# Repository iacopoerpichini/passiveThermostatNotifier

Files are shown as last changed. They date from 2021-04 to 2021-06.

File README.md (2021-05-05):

# passiveThermostatNotifier



### About

This project provides a new interface for notifications using the idea of Ubiquitous Computing in smart home system.
It is realized with a Micro Controller with a Wi-fi module onboard, it is designed for all type of sensor and show the notification in passive way with a RGB Wi-Fi bulb.
In this case the bulb is related to a temperature sensor and the notification are about how much cold or hotter the house is.
The thermostat system it is built using low-cost components and Open Source platformsto make it reproduced by everyone.

In this project are developed a physical device and an interface via a Telegram bot.

The [documentation.pdf](https://github.com/iacopoerpichini/passiveThermostatNotifier/blob/master/documentation.pdf) provided can be used like a manual to build the whole system.

### Directories Layout

```bash
├── 3DModel                             # contains two file tipe of box model
│   ├── stl
│   ├── ctb
├── Sensor Library and Examples         # a series of sensors library to remake this project
│   ├── DHT                             # sensor used in thermostat device          
│   ├── ...
├── UniversalTelegramBot-1.3.0 Library  # used to make the Telegram bot
├── img                                 # image used in readme/paper
│   ├── ...
├── documentation.pdf                   # guide to reproduce all the work
├── firmaware.ino                       # node mcu v1.0 firmware made with arduino ide
```

#### Device
The device can be installed in an environment connected to a smart bulb that changes color and light intensity in relation to the temperature measured by a sensor.
The light bulb color changes slowly.
The device has a temperature sensor, a WiFi connection, a buzzer to receive active notification via interaction with an interface and a button to stop the change of color bulb.
There is also a build-in led that displays in real time the state of the temperature sensor.
#### Render of 3D model
In this repo are provided all the 3D file used to print the cover of the device.

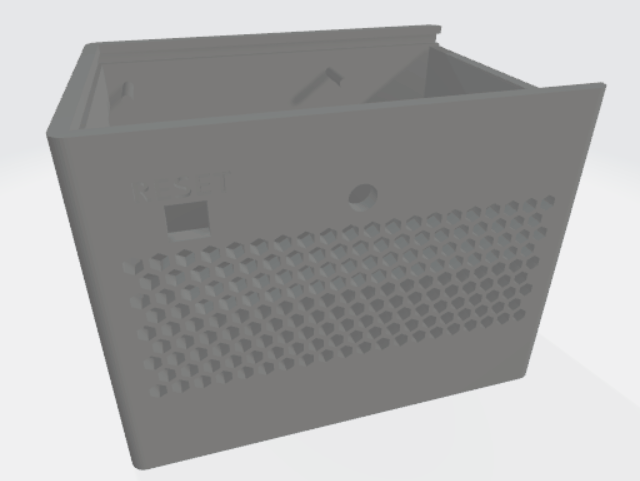
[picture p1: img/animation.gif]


#### Telegram bot
The bot allows users to get real-time information about temperature and humidity.
Furthermore, it is also possible to select the desired temperature bound to change the bulb color.
By default, temperature bounds are set on [16,24] Celsius degree.
The bulb turns to red slowly if the temperature is higher than 24 degree and turns blue if is lower than 16 degree.
It is also possible to notify people near the sensor with a buzzer.

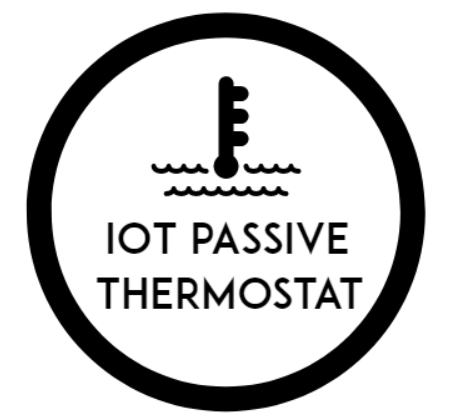
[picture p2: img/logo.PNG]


To create a Telegram bot:
  1. Open BotFather available at this [link](https://t.me/botfather)
  2. Click the start button and type `/newbot`.
    - Then follow the instructions to create your bot. Give it a name and username.
  3. If your bot is successfully created, you’ll receive a message with a link to access the bot and the bot token.

Anyone that knows your bot username can interact with it. 

To make sure that the bot ignore messages that are not from any authorized users, you can get your Telegram User ID.
Then, when your telegram bot receives a message, the ESP can check whether the sender ID corresponds to your User ID and handle the message or ignore it.
Open [IDBot](t.me/myidbot) and type `/getid` and use it in the firmware.

#### ThingSpeak

The device also use a ThingSpeak channel available [here](https://thingspeak.com/channels/1367465) to display all the data collected.

To make a Channel follow the[ThingSpeak Official Documentation](https://www.mathworks.com/help/thingspeak/collect-data-in-a-new-channel.html).

### Requirements
| Software | Version |
| ---|---|
| **Arduino IDE** | tested on v1.8.3 | 
| **ESP8266** | tested on v2.5.2 | 
| **ArduinoJson** | tested on v6.17.3 | 
| **Universal Telegram Bot Library** | tested on v1.3.0 | 

To install ESP8266 Add-on in Arduino IDE:
  1. Go to File > Preferences
  2. Enter `http://arduino.esp8266.com/stable/package_esp8266com_index.json` into the “Additional Boards Manager URLs” field. Then, click the “OK” button.
  3. Open the Boards Manager. Go to Tools > Board > Boards Manager
  4. Search and install ESP8266 by ESP8266 Community library
  5. Use Generic ESP8266 Board in Tools
  
Also install the ArduinoJson and Universal Telegram Bot Librarys.

  1. Go to Skech > Include Library > Manage Libraries.
  2. Search library.
  3. Check the version and install the library.

### Usage
The first part of the Sketch is a highly commented setup code
There are some global variables that need to be changed.
These parameters are the Network SSID and password, the IP address of light bulb, the Telegram credential mentioned before and an extra public API token to make an integration with ThingSpeak, which is an optional tool.

After you have flash the code on the device and built the circuit, start chatting with the bot.

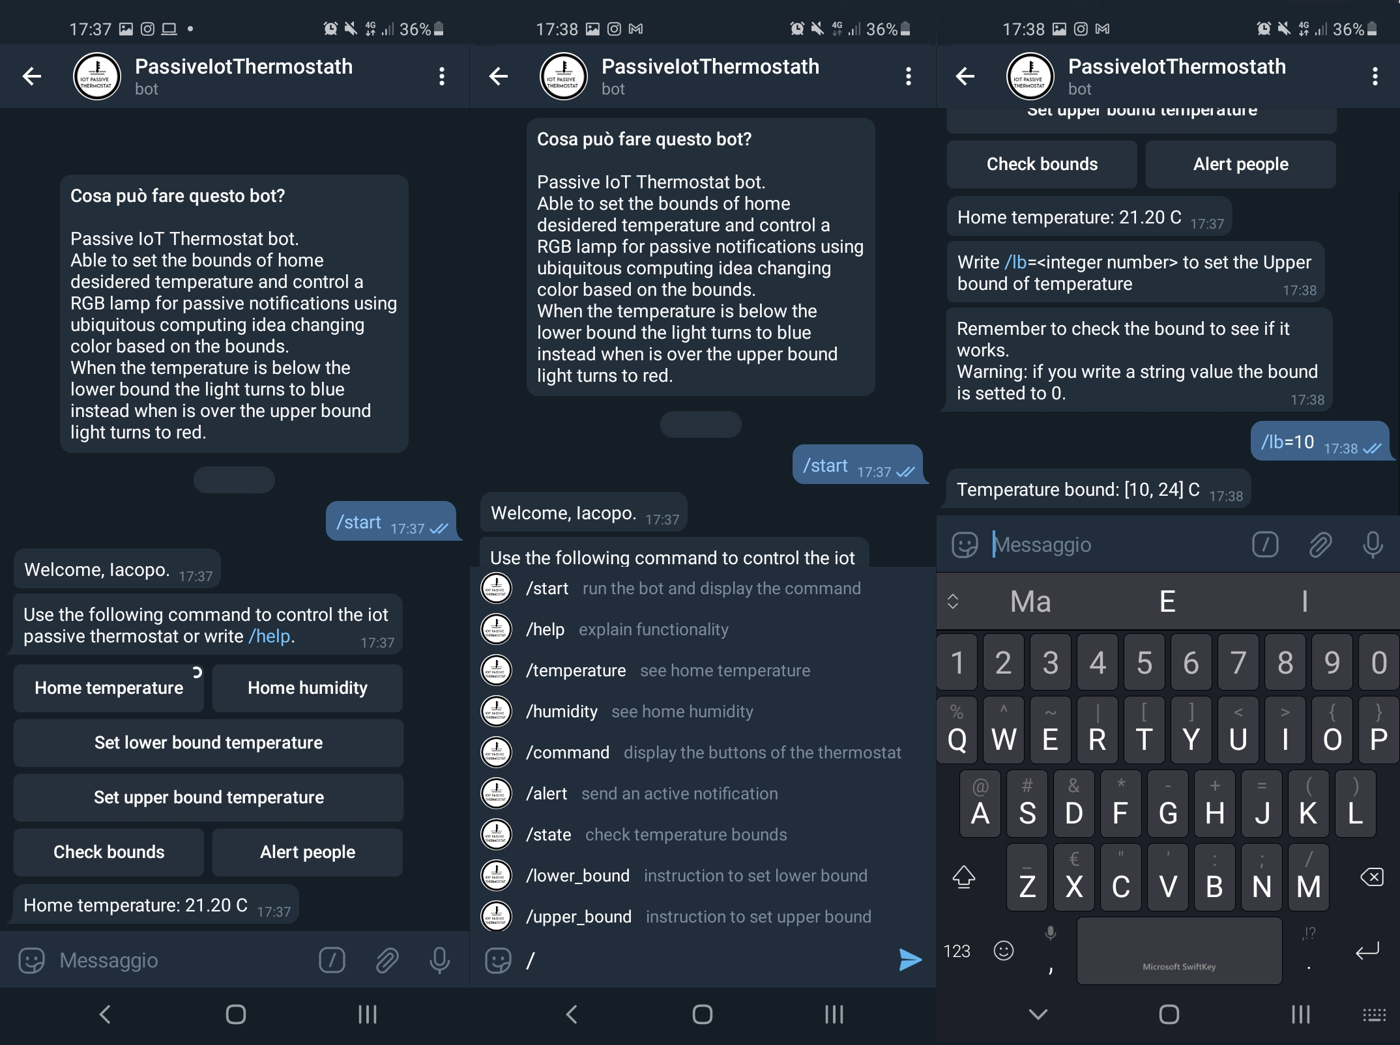
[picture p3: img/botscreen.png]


### The Telegram Keyboard
Most of the commands in the telegram Keyboard are displayed.

| Command | Description |
| ---|---|
| **/start** | run the bot and display the command| 
| **/help** | explain functionality | 
| **/temperature** | see home temperature | 
| **/humidity** | see home humidity | 
| **/command** | display the button of thermostat | 
| **/alert** | send an active notification | 
| **/state** | check temperature bound | 
| **/lower_bound** | instruction to set lower bound |  
| **/upper_bound** | instruction to set upper bound | 
| **/lb=\<Integer\>** | real method to set lower bound | 
| **/ub=\<Integer\>** | real method to set upper bound | 

#### Thanks
I want to thank my childhood friend Andrea for giving me the opportunity to 3D print the model.

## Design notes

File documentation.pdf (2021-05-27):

# IoT Thermostat with Passive Notification System

Iacopo Erpichini
Universita degli Studi di Firenze ` Computer Engineering
iacopo.erpichini@stud.unifi.it

Abstract—This paper provides a new interface for notifications using the idea of Ubiquitous computing in a smart home system. It is realized with a Micro Controller with a Wi-fi module on board, it is designed for all types of sensors and shows the notification passively with an RGB Wi-Fi bulb. In this case, the bulb is connected to a temperature sensor and the notification are about the measured temperature by the sensor. Substantially how much cold or hot the house is. The thermostat system is built using low-cost components and Open Source platforms to make it reproducible by everyone.
In this project have been developed a physical device and an interface via a Telegram bot.
Index Terms—IoT, NodeMcu ESP-12, Arduino, Ubiquitous computing, domotic system, Telegram
I. INTRODUCTION

The Internet of Things is creating much buzz while it goes about transforming our lives. IoT is everywhere, even though we do not always see it or know that a device is part of the IoT. Furthermore, the Internet of Things is turning physical object into a complete ecosystem of information, shared between devices that are wearable, portable, and even implantable, turning our lives rich of technology and data.
Nowadays, the smartest IoT home automation devices allow users to control them via an app or even via voice commands. The purpose of this paper is to build a IoT system for passive notification using the idea of Ubiquitous computing [1] (or ”ubicomp”) that is a concept in software engineering and computer science where computing is made to appear anytime and everywhere.
In this case the system wants to control a simple IoT device that is an RGB bulb with Wi-Fi module build in to make passive notification using the property of the bulb of changing color and brightness in a certain range of time.
The core of the system is a chip named Node Mcu v1.0 ESP-12 presents in Figure [1].
The system is designed to be built using low-cost components and Open Source platforms in such a way as to be simply reproduced by a user with few computer skills.
The micro controller can be programmed via Arduino IDE [2], the code is written in C++ with an addition of special methods, functions and libraries, to integrate every sensor of the project. The ’sketch’ (the name given to Arduino code files) created, it is processed and compiled to machine language and flashed on board via the IDE.

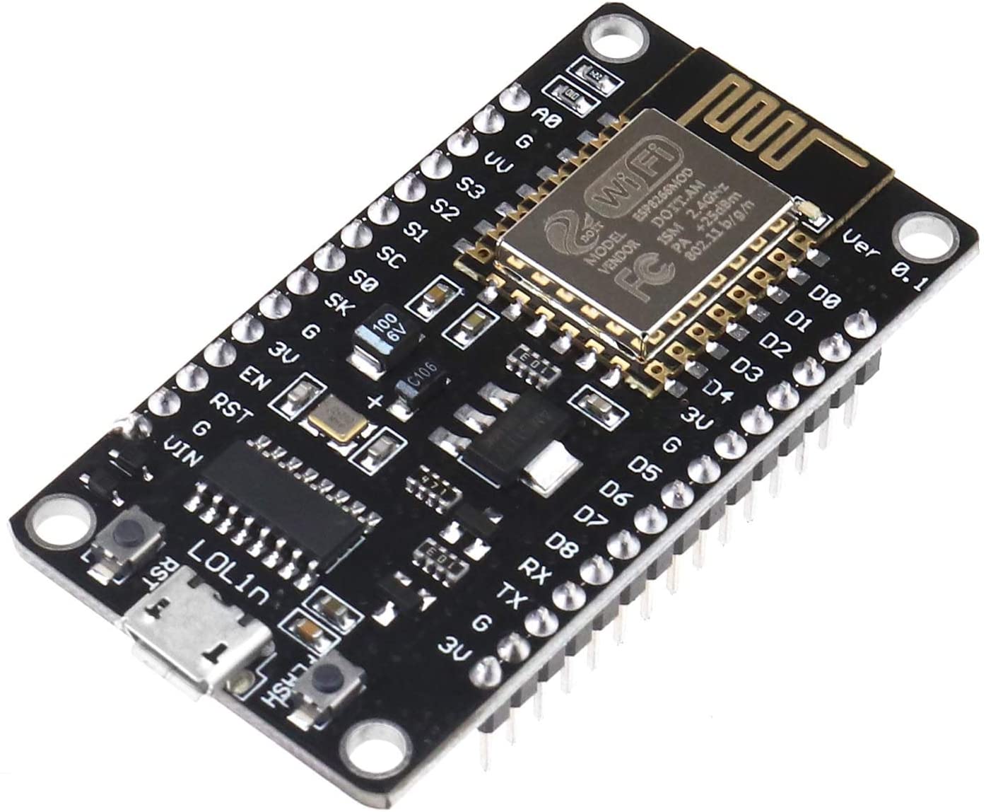
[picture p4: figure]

Fig. 1. Node Mcu V1.0 ESP-12 with ESP 8266 Wi-Fi chip on board.

The entire code and more instruction to reproduce the system are on GitHub repo [8], the entire code has been made in the most generic way.
It is designed to be able to change the operation of the system, for example replacing the temperature sensor with a gas detection sensor or with an infrared sensor.

II. SYSTEM DEVELOPMENT

The system has two main pieces:
- Device: The aim is to provide a device that can be installed in an environment connected to a smart bulb that changes color and light intensity in relation to the temperature measured by a sensor.
The light bulb color changes slowly over a long period of time otherwise we would not have the effect of passive notification, but more a kind of stroboscopic effect.
The device has a temperature sensor, a WiFi connection, a buzzer to receive active notification via interaction with an interface and a button to stop the change of color bulb. There is also a build-in led that displays in real time the state of the temperature sensor.
- Interface: The interface is realized through a Telegram Bot, using Universal Telegram Bot library [3] to interact directly with the micro controller and its sensors from the outside.
This allows users to get real time information about temperature and humidity and to select a bound of desired temperature to change the color of the bulb.
By default the temperature bounds are set on [16,24] Celsius degree. The bulb turns to red slowly if the temperature is higher than 24 degree and turns blue if is lower than 16 degree.
It is also possible to notify people near the sensor with a buzzer.
In conclusion this system allows us to passively notify users who are in the room where this smart bulb is installed simply through the change of color and light intensity of the smart lamp, the color change must not be invasive so it is carried out over a medium-long period of time.
The temperature of the house where it is installed needs to be changed through a classical thermostat.

III. HARDWARE COMPONENT

A. Node Mcu v1.0 ESP-12
This micro controller has on board the ESP8266 Wi-Fi module and it is basically a System on Chip (SoC). It has Lua based firmware which is used to develop IoT applications. It is easy to work on this inexpensive SoC and make our device smart.
The development board reported is useful for the cable management when the system is build.

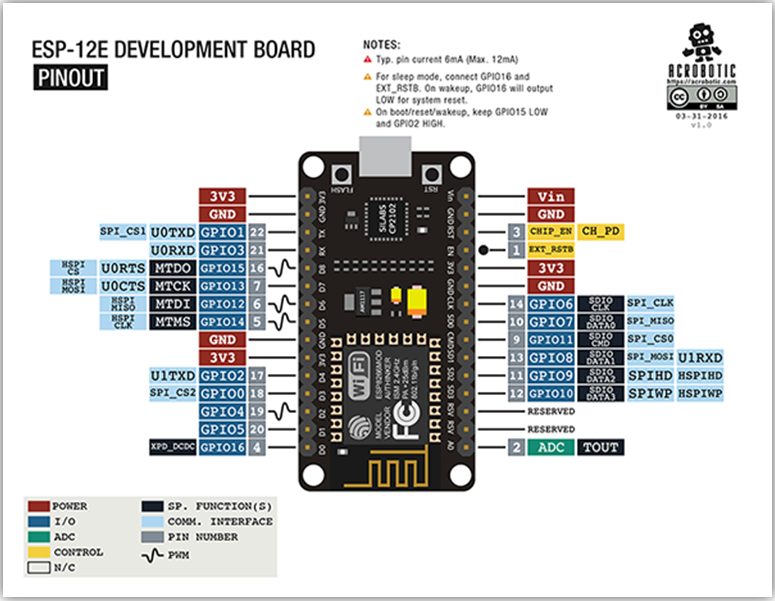
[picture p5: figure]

Fig. 2. Node Mcu V1.0 ESP-12 datasheet pin-out.

ESP-12 is the heart of the project, it allows us to connect to the internet and fully manage all the sensors connected to it. Furthermore, once connected to the Wi-Fi of the environment in which it is located, the chip runs the instance of the Telegram Bot used to control the sensor.

B. DHT-22
The DHT-22 is a basic, low-cost, digital, temperature and humidity sensor. It uses a capacitive humidity sensor and a thermistor to measure the surrounding air, and spits out a digital signal on the data pin. It is fairly simple to use, but requires careful timing to gather data.
Regrettably, the sensor is able to send new data only once every two seconds.

The system uses it toto monitor the temperature and control the led on board and a smart bulb. If the measured temperature is higher or lower than the bounds, saved in the micro controller, the light changes colors.

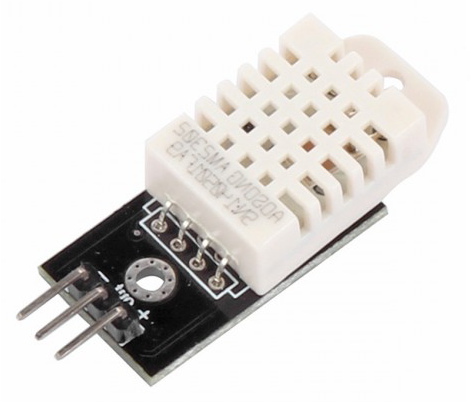
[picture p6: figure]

Fig. 3. DHT 22 Sensor for Temperature and Humidity

C. RGB Led Common Anode
This is an RGB led installed on the device that displays the state of it in real time: the light color is green if the temperature measured in real time is in the bounds; it turns blue or red if the temperature is respectively under or over the bounds. RGB led are of two types: some have common positive terminal (anode) and some have common negative terminal (cathode).
Since the LED’s legs are the same in appearance, it is possible distinguish them according to their functioning attached to a power supply. The terminal is the longest leg of the led.

Fig. 4. RGB Led Common Anode

D. Philips Hue
Philips Hue RGB is the bulb controlled by the device for the color changing notification system.
According to the Philips documentation of Hue [4], the bulb can be controlled via HTTP request .

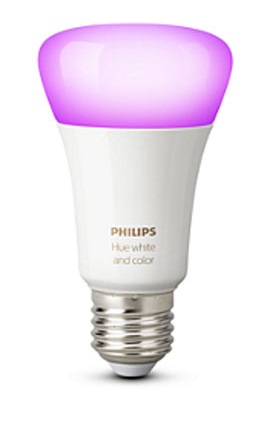
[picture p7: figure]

Fig. 5. Philips Hue Rgb bulb

E. Piezo Buzzer

The Piezo buzzer produces sound based on reverse of the piezoelectric effect. The generation of pressure variation or strain by the application of electric potential across a piezoelectric material is the underlying principle.
This buzzer is used to actively notify people near the IoT device.

Fig. 6. Piezo Buzzer

F. Push Button

The push button is a component that connects two points in a circuit when it is pressed.
The user can change the temperature bound by holding the button. The success of this action is notified by a red blink of the device’s LED.
This is useful because if a user sees the light turning to red or blue but doesn’t want to open the telegram bot and change the temperature bound, user can press the button and the upper bound is incremented by a value chosen in the firmware of the micro controller and lower bound is decremented of this value.

Fig. 7. Mini switch push button

G. Li-Po Battery 3.7 V

A lithium polymer battery (Li-Po), is a rechargeable battery of lithium-ion technology using a polymer electrolyte instead of a liquid electrolyte.
It is connected to the Node Mcu at Vin and Gnd pin of the board to power the system without cable.

Fig. 8. Li-Po Battery 3.7 V

H. Other component
For this circuit is necessary to have other components such as; a transistor NPN 2n2222 to help life during of buzzer, jump wires, resistor, a breadboard and a USB to mini USB cable to flash the firmware on the micro controller.
To make the same circuit choose the resistor used according with a resistor color table.

IV. CIRCUIT
The circuit was initially designed to be built with an Arduino Uno connected to an ESP8266 (Figure [12]), effectively using the Arduino as a bridge to flash the firmware on the Wi-Fi chip.
This initial circuit was subsequently discarded since the properties of the Arduino were not completely used and was more complex and more expensive than using an ESP-12 micro-controller.
The final result can be showed in Figure [13]. This chip has directly on board the Wi-Fi module and it can be programmed in the same way as an Arduino.
A. 3D Model
Once the circuit had been designed, it also was decided to create a physical box to contain the sensors and the micro controller itself.
This model was designed using a 3D modeling software and then was printed on a Stereolithographic printer.

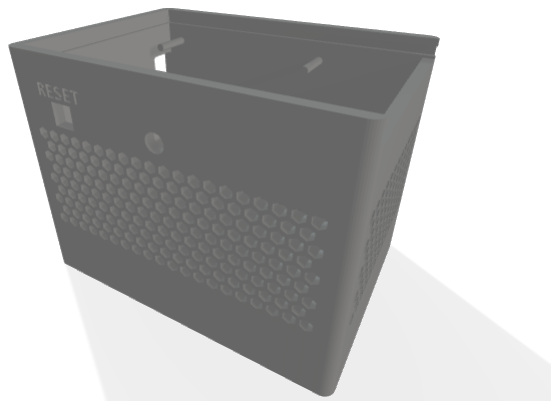
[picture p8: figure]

Fig. 9. Render of the box that contains the circuit without top cover.

Instead of using powder or filament, Stereolithography technology uses a liquid resin to produce 3D prints. The 3D files are provided in the GitHub Repository. In Figure [17] there is the result of 3D print.

B. Other ideas
The code for this project was written to be modeled by users with computer skills to reproduce the idea of Ubiquitous Computing in other types of sensors.
Still using a light bulb connected to the micro controller, two other circuit diagrams are provided:

- The first circuit shows how to build a gas detection sensor that monitors air quality Figure [14].
- The second is an infrared sensor that could be used as an anti-theft / alarm if connected near a door Figure [15].
V. SOFTWARE

The software side is composed by two parts: the sketch that controls the physical device and the interface provided via the Telegram bot.
As mentioned before, the code has been written to be as simple and generic as possible and has been heavily commented. This is because the device was designed to be replicated or extended in functionality.
A. Telegram Bot
Telegram is a freeware, cross-platform, cloud-based instant messaging (IM) software and application service. The service also provides end-to-end encrypted video calling, VoIP, file sharing and several other features.
An interesting feature are chat bots. There are third-party applications that run inside Telegram. Users can interact with bots by sending them messages, commands and inline requests. Bots are controlled using HTTPS requests to Telegram Bot API [3].
Telegram allows the user to create a chat bot using one of it called BotFather; simply by sending the command /newbot and following a few simple instructions, an instance of a bot will be generated that is accessible through a unique bot token. Subsequently, the code capable of interpreting the desired commands will be loaded on the micro controller.

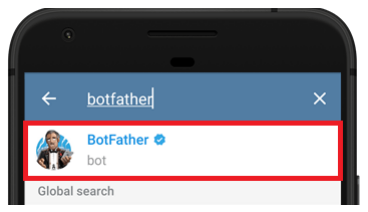
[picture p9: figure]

Fig. 10. Bot Father used to create bot in Telegram.

Anyone that knows the bot username can interact with it. To make sure that the generated bot ignore messages that are not from any authorized users, it is possible to get Telegram User ID with another bot with the command /getid.

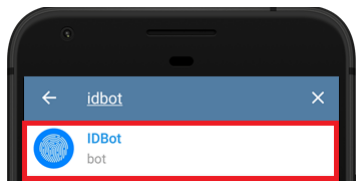
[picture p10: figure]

Fig. 11. IdBot a bot that allows user to get personal Telegram ID.

At this point with the two unique credentials it is possible to initialize the connection between the micro controller and Telegram in a safe way.

The features of the bot are simple and are shown in Figure [16], it is possible to control the temperature and the humidity detected by the device. Also, it is possible to set and check the desired temperature bound. At least, in case of emergency or to actively notify users near the device it is possible to reproduce an alarm sound.

B. Flash device

The code named firmware.ino is flashed in a ESP-12 micro controller. To make this possible is necessary to install an add-on for ESP8266 [5] for the Arduino IDE that allows users to program the ESP8266 using the Arduino IDE and its programming language.
The only thing to be done is to plug a board to a computer. Make sure to have the right port selected then click the “Upload” button in the Arduino IDE.
C. Sketch Arduino

The first part of the Sketch is a highly commented setup code, in fact there are some global variables that need to be changed.
These parameters are the Network SSID and password, the IP address of light bulb, the Telegram credential mentioned before and an extra public API token to make an integration with ThingSpeak which is an optional tool.
The main parts of the Sketch are:
- setup() function: is executed once, it sets the initial parameters and establish the connection with local network.
- loop() function: the listener of all events. When a message is written to the bot the loop passes it to handleNewMessages() function, also the loop check the temperature bounds that are local variables of micro controller and set the Hue bulb color and brightness.
- handleNewMessages(): defines all the actions of the telegram bot; the layout of keybord button sent to a user that messages with the bot. In the end, responds to all the messages that are arrived at the micro controller via Telegram.
- setHue(String Command): sets the color of the hue bulb. The Command is a String that represent a JSON with the hue parameters according to hue documentations. The command is sent to the light bulb with an HTTP GET request.
- uploadTemperatureHumidity(): sends an HTTP request like for the Hue to a site named ThingSpeak.
It is used to save IoT data in cloud and make simple statistics based on the time course of the measurements.
D. ThingSpeak for IoT Projects

ThingSpeak is a free Data collection in the cloud with advanced data analysis using MATLAB software. Here is possible to see the application of use at this problem [6]. ThingSpeak enables sensors, instruments, and websites to send data to the cloud where they are stored in either a private or a public channel. Once data are in a ThingSpeak channel, users can analyze and visualize it, calculate new data, or interact with social media, web services, and other devices. Make a public channel with this tools is very simple (Guide [7]). Once created, the site provided to the user a Write API Key and a Read API Keys, for this project the site was used to create a history of the temperature and humidity data detected by the device.

VI. USABILITY TESTS

The last phase of development focused on an evaluation of the prototype through a usability analysis. Two types of test were implemented.
The first one concerns a user without computer skills who finds the system completely assembled in his home. User tests chat bot and check if the prototype made is sufficiently userfriendly.
While the second one is aimed at users with IT skills and consists in replicating the whole system or circuit assembly, flashing the firmware once modified the code with local parameters and creating the Telegram bot as are explained in this article.
a) Test 1: The questions presented are SEQ type, with a scale ranging from 1 to 7, where 1 represents Strongly disagree and 7 Strongly agree. Furthermore, all the tasks are of the “closed” type, that is, there is only one procedure to carry them out.
The test was submitted at 8 people that have an age between 24 and 58 years old.
b) Test 2: This test is provided with this paper used like a sort of guide to assembly the circuit and retrieve information for all the questions.
The questions are about the assembly of the circuit, the creation of the view in ThingSpeak, the creation of Telegram Bot and using of Arduino IDE.
The test was submitted at two people with IT skills in particular one is passionate about the Arduino world, one is a computer engineer.

VII. TEST RESULT

Here are reported the results of the tests carried out. It is possible to find the detailed results with all the answers in the GitHub repository.

TABLE I
TEST 1 RESULT
Question | Mean Rating | σ
Find Bot on Telegram app and start messaging | 6.75 | 0.187
Retrieve information about Temperature | 6.875 | 0.109
Retrieve information about Humidity | 6.875 | 0.109
Change Thermostat Bound | 5.125 | 1.109
Check Thermostat Bound | 6.375 | 0.734
Launch the alarm through bot | 6.75 | 0.187
Reset physical device | 6.375 | 0.484
The system is easy to learn | 6 | 0.5
Overall, I am satisfied the system | 6.125 | 0.359

TABLE II
TEST 2 RESULT
Question | Mean Rating | σ
Build the circuit | 6 | 1
Analyze firmware.ino code and change parameters | 7 | 0
Install add-on in Arduino IDE | 6.5 | 0.25
Flash the ESP 12 | 7 | 0
Create Telegram Bot | 7 | 0
Create ThingSpeak Channel | 6 | 1

VIII. CONCLUSION
The proposed system allows to have a physical device for passive notification of the temperature in a room. In addition, it allows users to have an IoT interface that can be remotely controlled via a highly customizable Telegram Bot.
A negative aspect that emerges from the first test is related to the setting of the bounds.
Unfortunately, the Telegram API only provides an interaction via text commands and therefore to set a bound, for example the lower one, it was decided to do it via a text string with the command /ub=<intger number>. This behavior could be simplified if, for example, Telegram provides new API with a number picker linked to a text command or to a button.
The system is designed to be replicated by a user who has IT skills to make a standard environment smarter in every home.The test submitted to the two people that have IT skills confirms this result.
Furthermore, home automation is becoming increasingly popular and finding low-budget solutions will become more and more frequent.

IX. FUTURE WORK
This project has been entirely designed to be modular and extensible. The idea of passive notification using a light bulb can be used in many fields as reported in the circuits shown earlier in this report.

REFERENCES

[1] Ubiquitous Computing, (https://en.wikipedia.org/wiki/Ubiquitous_computing) Wikipedia
[2] Arduino IDE download, (https://www.arduino.cc/en/software) Arduino site
[3] Universal Telegram Bot library, (https://github.com/witnessmenow/Universal-Arduino-Telegram-Bot) GitHub, Brian Lough
[4] Philips Hue specification, Philips Hue Site (https://developers.meethue.com/develop/get-started-2/)
[5] ESP8266 Library, (https://github.com/esp8266/Arduino) ESP8266 Community, Official Arduino
[6] ThingSpeak for IoT Projects, PassiveIotThermostat Public Channel,Channel (https://thingspeak.com/channels/1367465)
[7] ThingSpeak Official Documentation, Make a Channel, link (https://www.mathworks.com/help/thingspeak/collect-data-in-a-new-channel.html)
[8] GitHub Repository of Passive Thermostat Notifier,link, (https://github.com/iacopoerpichini/passiveThermostatNotifier) Iacopo Erpichini

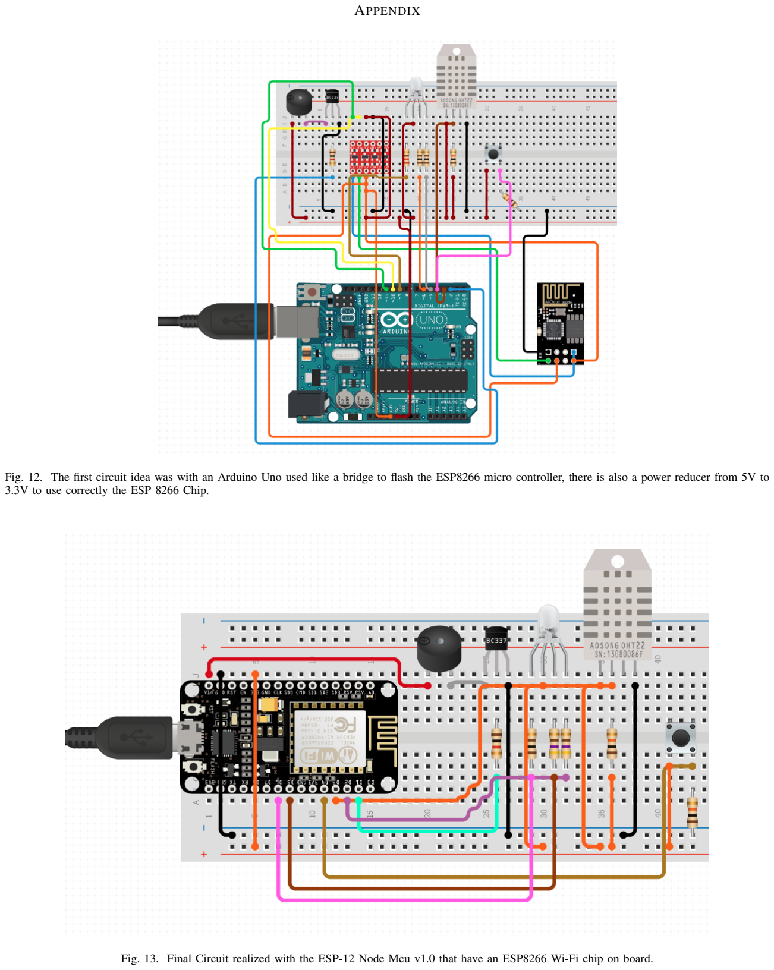
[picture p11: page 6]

APPENDIX

Fig. 12. The first circuit idea was with an Arduino Uno used like a bridge to flash the ESP8266 micro controller, there is also a power reducer from 5V to 3.3V to use correctly the ESP 8266 Chip.

Fig. 13. Final Circuit realized with the ESP-12 Node Mcu v1.0 that have an ESP8266 Wi-Fi chip on board.

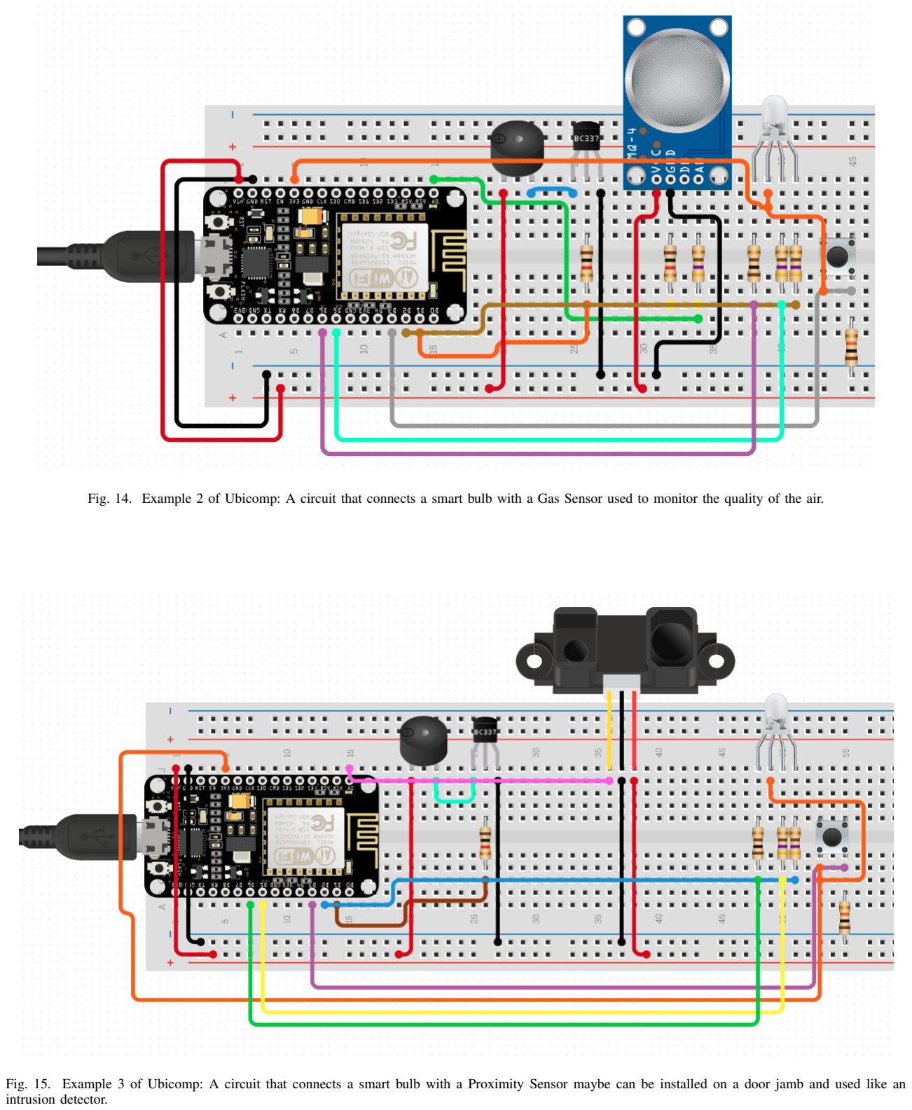
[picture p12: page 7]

Fig. 14. Example 2 of Ubicomp: A circuit that connects a smart bulb with a Gas Sensor used to monitor the quality of the air.

Fig. 15. Example 3 of Ubicomp: A circuit that connects a smart bulb with a Proximity Sensor maybe can be installed on a door jamb and used like an intrusion detector.

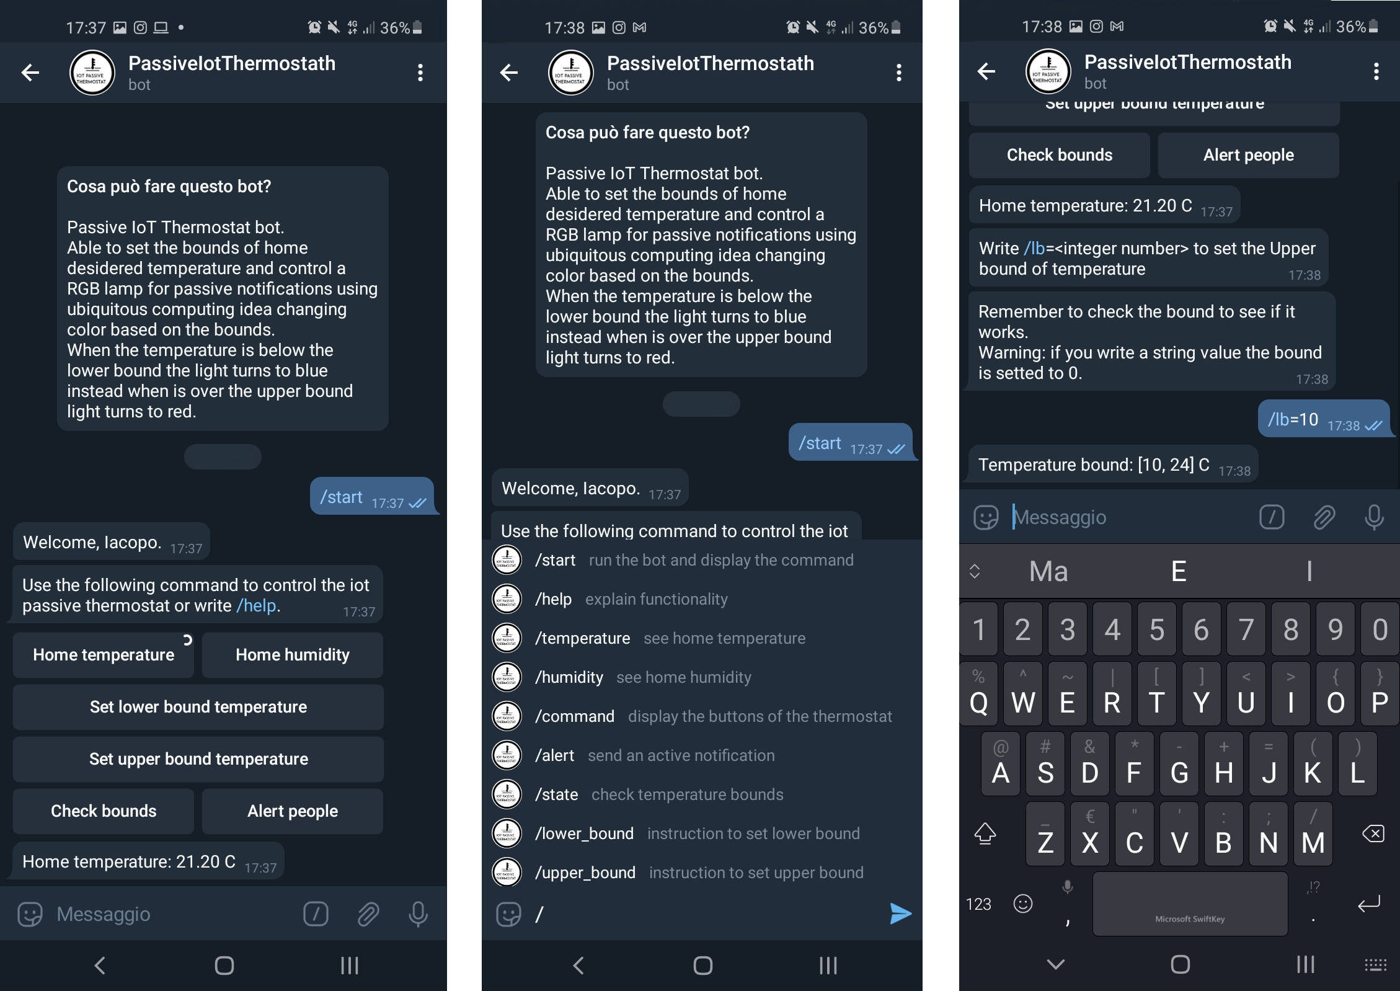
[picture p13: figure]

Fig. 16. PassiveIotThermostat bot. The bot send to the user a button keyboard to interact with the device. It is also possible to message him with the keywords suggested by typing ”/”.

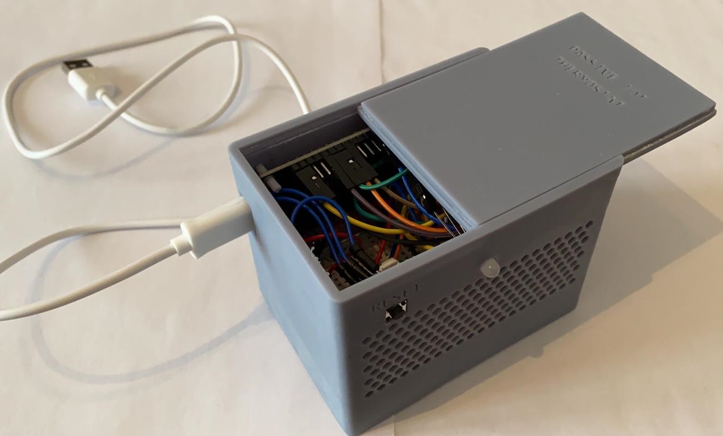
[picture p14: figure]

Fig. 17. Passive IoT Thermostat device assembled.

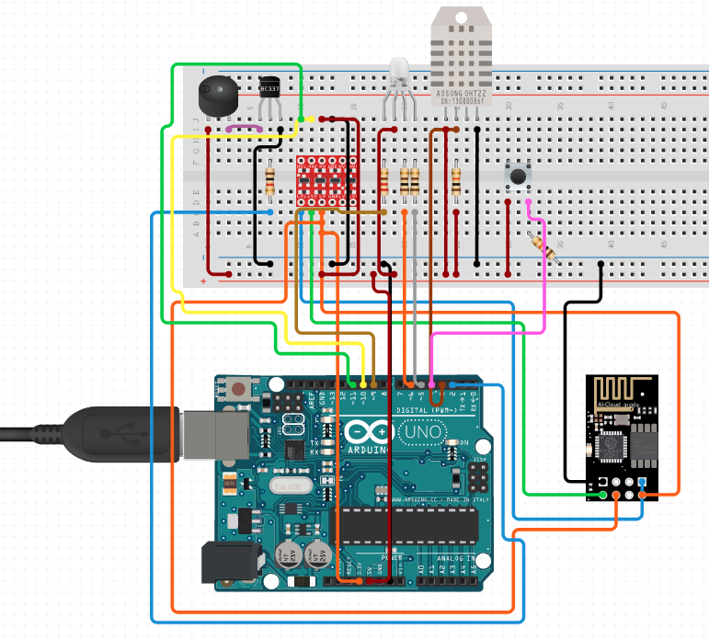
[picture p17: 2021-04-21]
img/arduino+esp8266.png

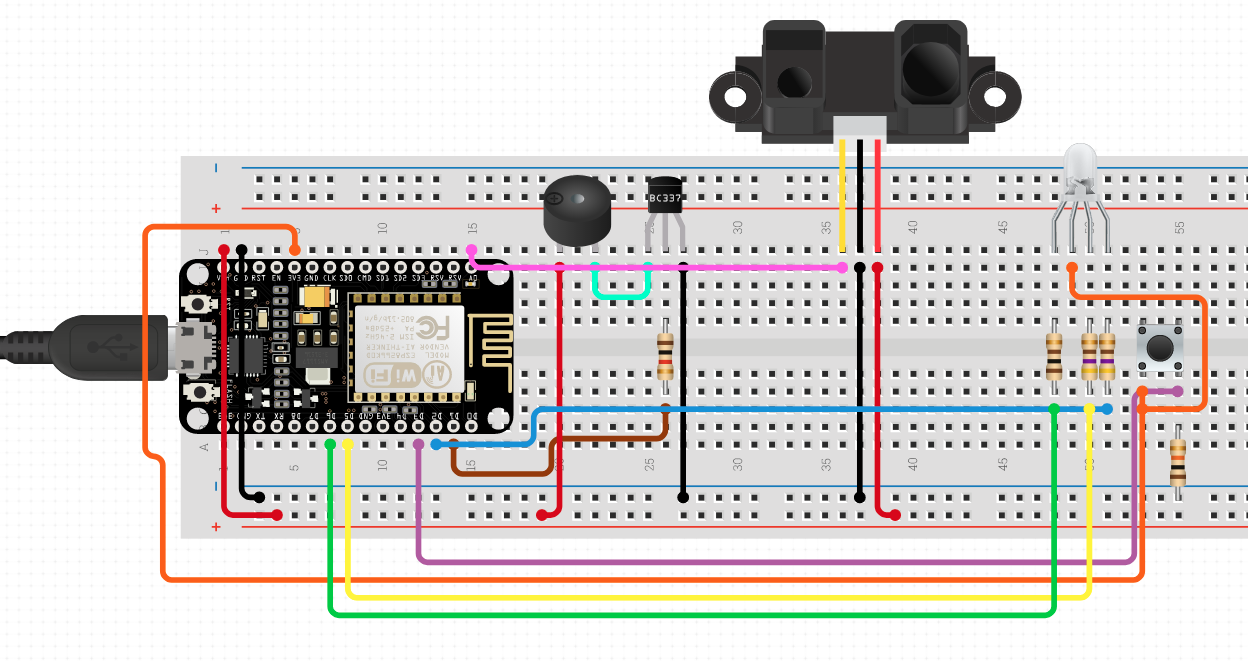
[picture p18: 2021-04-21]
img/proximitySensor.png

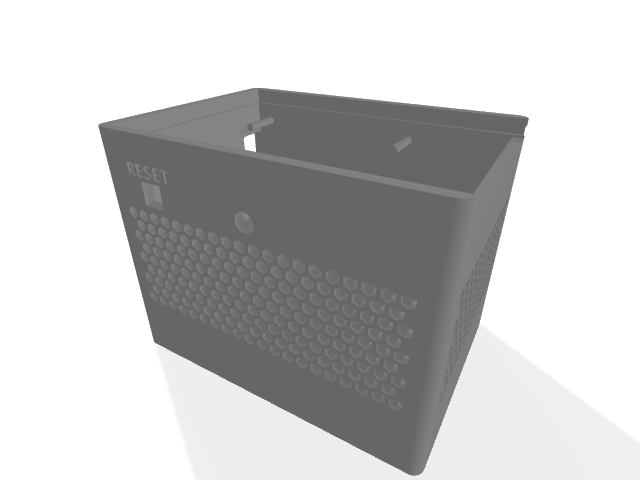
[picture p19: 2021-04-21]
img/scatola.png

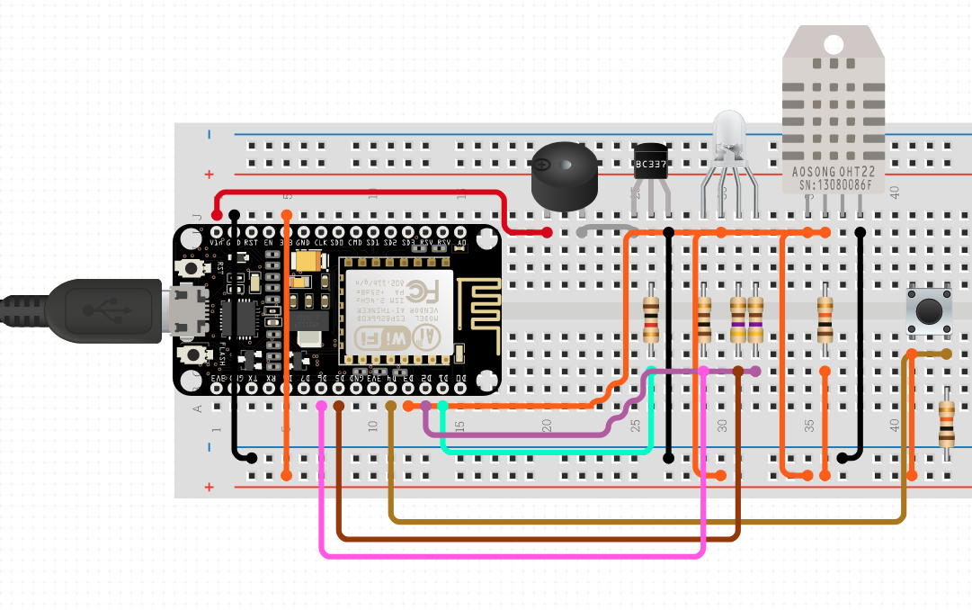
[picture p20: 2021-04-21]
img/final_circuit.png

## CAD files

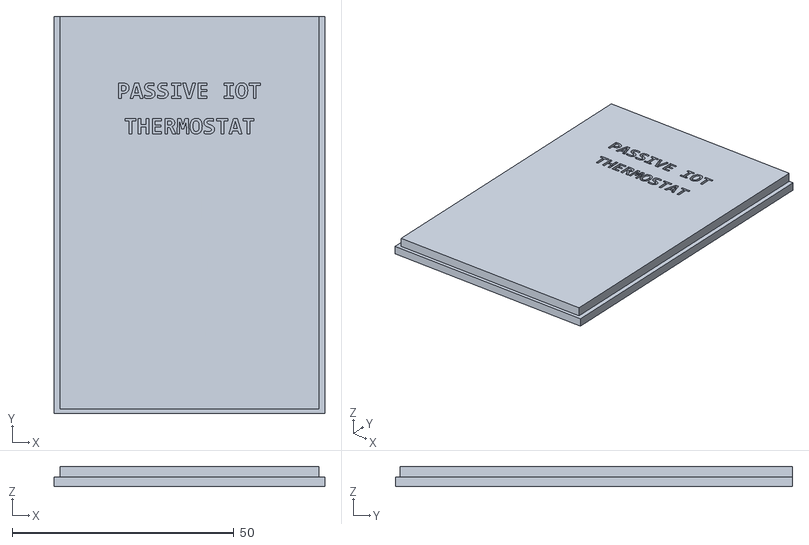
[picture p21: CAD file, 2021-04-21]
3D Model/stl/cover.stl
61.0 x 89.5 x 4.60

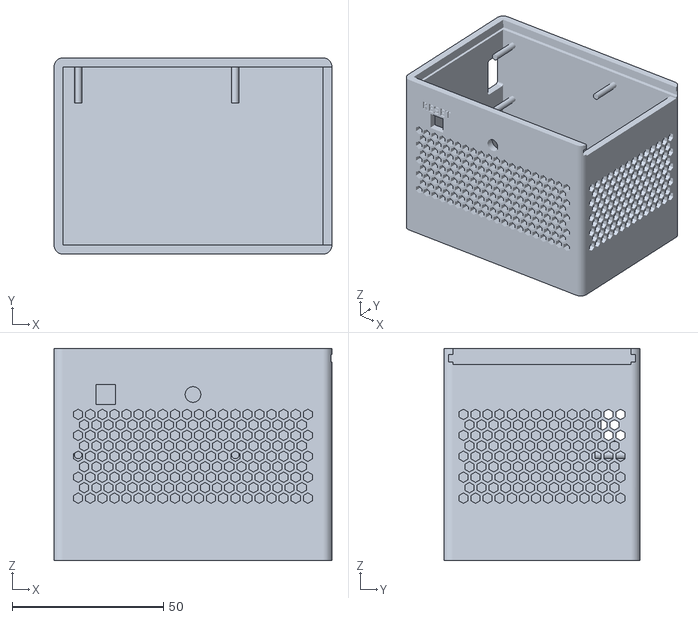
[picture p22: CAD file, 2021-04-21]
3D Model/stl/box.stl
92.0 x 65.0 x 70.3

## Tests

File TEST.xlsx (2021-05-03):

TEST 1
 | Person 1 | Person 2 | Person 3 | Person 4 | Person 5 | Person 6 | Person 7 | Person 8
Age | 25 | 26 | 26 | 25 | 54 | 56 | 49 | 22 | Mean | Var
Task 1 | 7 | 7 | 7 | 7 | 6 | 6 | 7 | 7 | 6.75 | 0.1875
Task 2 | 7 | 7 | 7 | 7 | 7 | 6 | 7 | 7 | 6.875 | 0.109375
Task 3 | 7 | 7 | 7 | 7 | 7 | 6 | 7 | 7 | 6.875 | 0.109375
Task 4 | 6 | 5 | 6 | 6 | 3 | 4 | 5 | 6 | 5.125 | 1.109375
Task 5 | 7 | 7 | 7 | 7 | 5 | 5 | 6 | 7 | 6.375 | 0.734375
Task 6 | 7 | 7 | 7 | 7 | 6 | 6 | 7 | 7 | 6.75 | 0.1875
Task 7 | 7 | 7 | 6 | 7 | 6 | 5 | 6 | 7 | 6.375 | 0.484375
Task 8 | 7 | 6 | 6 | 6 | 5 | 5 | 6 | 7 | 6 | 0.5
Task 9 | 6 | 6 | 6 | 7 | 6 | 5 | 6 | 7 | 6.125 | 0.359375
TEST 2
 | Person 1 Comp Eng | Person 2 Passionate Arduino
Age | 26 | 24 | Mean | Var
Task 1 | 5 | 7 | 6 | 1
Task 2 | 7 | 7 | 7 | 0
Task 3 | 6 | 7 | 6.5 | 0.25
Task 4 | 7 | 7 | 7 | 0
Task 5 | 7 | 7 | 7 | 0
Task 6 | 7 | 5 | 6 | 1

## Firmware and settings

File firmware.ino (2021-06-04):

/**
  Iacopo Erpichini

  IoT node for passive notification about temperature with a remote control using telegram bot

  Project created using Brian Lough's Universal Telegram Bot Library: https://github.com/witnessmenow/Universal-Arduino-Telegram-Bot

  Programmed on a node mcu v1 board with esp8266: https://github.com/esp8266/Arduino
*/

#ifdef ESP32
#include <WiFi.h>
#else
#include <ESP8266WiFi.h>
#endif
#include <WiFiClientSecure.h>
#include <UniversalTelegramBot.h>   // Universal Telegram Bot Library written by Brian Lough: https://github.com/witnessmenow/Universal-Arduino-Telegram-Bot
#include <ArduinoJson.h>
#include "DHT.h"

/*************************************************************************+
 ****************** Node mcu v1.0 pin definitions *************************
 **************************************************************************/
const int ledRGBred = 12; // D6 on board
const int ledRGBgreen = 14; // D5 on board
const int ledRGBblue = 13; // D7 on board
const int buzzer = 5; // D1 on board
const int DHT_PIN_DATA = 0; // D3 on board
const int button = 15; //D8 on board
DHT dht(DHT_PIN_DATA);

/*********************************************************
 ****************** User setting *************************
 *********************************************************/

const char* SSID = "network_name";        // Replace with your network name
const char* PASSWORD = "password";       // Replace with your network psw


// Initialize Telegram BOT
#define BOTtoken "xxxxxxxxx:xxxxxxxxxxxxxxxxxxxxxxxxxxxxx"  // your Bot Token (Get from Botfather)

// Use @myidbot to find out the chat ID of an individual or a group
// Also note that you need to click "start" on a bot before it can message you
#define CHAT_ID "1040419680"
// used for security, this bot is yours no one can access to it only with the name
WiFiClientSecure client_bot;
UniversalTelegramBot bot(BOTtoken, client_bot);

//Hue constants // need to rename
const char hueHubIP[] = "192.168.0.50";  //Hue Bridge IP
const char hueUsername[] = "myhue";  //Hue username
const int hueHubPort = 80;

//Hue variables
IPAddress server(192, 168, 0, 50); // insert your hue ip
const int DELAY_HUE = 100000; //transaction time for hue

// Hue color in JSON format using hue, saturation and brightness
const String hueWhite = "{\"on\": true,\"hue\": 50100,\"sat\":255,\"bri\":255,\"transitiontime\":" + String(0) + "}";
const String hueRed = "{\"on\": true,\"hue\": 0,\"sat\":255,\"bri\":124,\"transitiontime\":" + String(DELAY_HUE) + "}";
const String hueBlue = "{\"on\": true,\"hue\": 200,\"sat\":255,\"bri\":124,\"transitiontime\":" + String(DELAY_HUE) + "}";
WiFiClient client_hue;

// THINGSPEAK integration
const char *host_thingspeak = "api.thingspeak.com";        //IP address of the thingspeak server
const char *api_key_thingspeak = "replace with yours";     //Your own thingspeak api_key
const int httpPort = 80;                                   //thingspeak port
long uploadTime = 60000;                                   //upload time for thingspeak every 60 sec
long differenceUpload = 0;
WiFiClient client_thingspeak;

/*********************************************************
 ************* Micro controller parameters ***************
 *********************************************************/

// progressive time in millis for transaction of change color to notify change state
const int CHANGE_DELAY = 5; // if higher the change is slower

// Checks for new messages every 1 second
int botRequestDelay = 1000;
unsigned long lastTimeBotRan;

// default variables for set the desired temperature in celsious
int lowerBound = 16;
int upperBound = 24;

// variables will change:
int buttonState = 0;         // variable for reading the pushbutton status

// led color
unsigned int green[3] = {0, 255, 0};
unsigned int red[3] = {255, 0, 0};
unsigned int blue[3] = {0, 0, 255};

/****************************************
 **************** CODE ******************
 ****************************************/

// setup of the micro controller
void setup() {
    Serial.begin(115200); // serial monitor 115200 baud
#ifdef ESP8266
    client_bot.setInsecure();
#endif
    // connect led rgb pin
    pinMode(ledRGBred, OUTPUT);
    pinMode(ledRGBgreen, OUTPUT);
    pinMode(ledRGBblue, OUTPUT);

    // add pin buzzer
    pinMode(buzzer, OUTPUT);

    // add pin button as input
    pinMode(button, INPUT);

    // Connect to Wi-Fi
    WiFi.mode(WIFI_STA);
    WiFi.begin(SSID, PASSWORD);
    while (WiFi.status() != WL_CONNECTED) {
        delay(1000);
        Serial.println("Connecting to WiFi..");
    }
    Serial.println(WiFi.localIP());     // Print ESP8266 Local IP Address

    while (!client_thingspeak.connect(host_thingspeak, httpPort)) {
        Serial.println("Connection Failed");
    }
}

// set a rgb color on led with my function it is possible to use RGB-1.0.5 libraries provided
void RGB_color(int red, int green, int blue) {
    analogWrite(ledRGBred, red);
    analogWrite(ledRGBgreen, green);
    analogWrite(ledRGBblue, blue);
}

// Handle what happens when you receive new messages
void handleNewMessages(int numNewMessages) {
    Serial.println("handleNewMessages");
    Serial.println(String(numNewMessages));

    for (int i = 0; i < numNewMessages; i++) {
        // Chat id of the requester
        String chat_id = String(bot.messages[i].chat_id);
        if (chat_id != CHAT_ID) {
            bot.sendMessage(chat_id, "Unauthorized user", "");
            continue;
        }

        // Print the received message
        String text = bot.messages[i].text;
        Serial.println(text);

        String from_name = bot.messages[i].from_name;
        String welcome = "Welcome, " + from_name + ".\n";

        String keyboardJson = F("[[{ \"text\" : \"Home temperature\", \"callback_data\" : \"/temperature\" },{ \"text\" : \"Home humidity\", \"callback_data\" : \"/humidity\" }],");
        keyboardJson += F("[{ \"text\" : \"Set lower bound temperature\", \"callback_data\" : \"/lower_bound\" }], ");
        keyboardJson += F("[{ \"text\" : \"Set upper bound temperature\", \"callback_data\" : \"/upper_bound\" }], ");
        keyboardJson += F("[{ \"text\" : \"Check bounds\", \"callback_data\" : \"/state\" }, { \"text\" : \"Alert people\", \"callback_data\" : \"/alert\" }]]");

        // emit an alert sound
        if (text == "/alert") {
            bot.sendMessage(chat_id, "Sound alert", "");
            for (int i = 0; i < 3; i++) {
                tone(buzzer, 1000); // Send 1KHz sound signal...
                delay(1000);        // ...for 1 sec
                noTone(buzzer);     // Stop sound...
            }
        }
            // return the current temperature
        else if (text == "/temperature") {
            float dhtTempC = dht.readTempC(); // Read temperature in Celsius, for Fahrenheit use .readTempF()
            String temp = String(dhtTempC);
            Serial.print(F("Temp: ")); Serial.print(dhtTempC); Serial.println(F(" [C]"));
            bot.sendMessage(chat_id, ("Home temperature: " + temp + " C"), "");
        }
            // return the current humidity
        else if (text == "/humidity") {
            float dhtHumidity = dht.readHumidity(); // Reading humidity in %
            String humidity = String(dhtHumidity);
            Serial.print(F("Humidity: ")); Serial.print(dhtHumidity); Serial.print(F(" [%]\t"));
            bot.sendMessage(chat_id, ("Home humidity: " + humidity + " %\t"), "");
        }

        if (text == "/testRGB") {
            bot.sendMessage(chat_id, "Test rgb led...", "");
            RGB_color(255, 0, 0); // Red
            delay(1000);
            RGB_color(0, 255, 0); // Green
            delay(1000);
            RGB_color(0, 0, 255); // Blue
            delay(1000);
            RGB_color(0, 0, 0);
        }

        if (text == "/upper_bound" || text == "/lower_bound") {
            if (text == "/upper_bound") {
                bot.sendMessage(chat_id, "Write /ub=<integer number> to set the Upper bound of temperature", "");
            } else {
                bot.sendMessage(chat_id, "Write /lb=<integer number> to set the Upper bound of temperature", "");
            }
            bot.sendMessage(chat_id, "Remember to check the bound to see if it works.\nWarning: if you write a string value the bound is setted to 0.", "");
        }

        // extract the substring for change the bound
        String action = text.substring(0, 3);
        String value = text.substring(4, 7);
        int bound = value.toInt();

        if (action == "/ub") {
            if (bound <= lowerBound) {
                bot.sendMessage(chat_id, "Warning: upper bound cannot be smaller than the lower bound.", "");
            } else {
                upperBound = bound;
                bot.sendMessage(chat_id, ("Temperature bound: [" + String(lowerBound) + ", " + String(upperBound) + "] C"), "");
            }
        }

        if (action == "/lb") {
            if (bound >= upperBound) {
                bot.sendMessage(chat_id, "Warning: lower bound cannot be bigger than the upper bound.", "");
            } else {
                lowerBound = bound;
                bot.sendMessage(chat_id, ("Temperature bound: [" + String(lowerBound) + ", " + String(upperBound) + "] C"), "");
            }
        }

        if (text == "/state") {
            bot.sendMessage(chat_id, ("Temperature bound: [" + String(lowerBound) + ", " + String(upperBound) + "] C"), "");
        }

        if (text == "/start" || text == "/command")
        {
            bot.sendMessage(chat_id, welcome, "");
            bot.sendMessageWithInlineKeyboard(chat_id, "Use the following command to control the iot passive thermostat or write /help.", "", keyboardJson);
        }

        if (text == "/help") {
            welcome += "The passive notification of this thermostat system is provided by a RGB lamp connected to the micro-controller.\n";
            welcome += "It is possible to set the bounds of home desired temperature and the RGB lamp will change color based on them.\n";
            welcome += "When the temperature is below the lower bound the light turns to blue instead when is over the upper bound light turns to red.\n";
            welcome += "There is the possibility to actively notify people in the house with an alert sound.";
            welcome += "\n\nFor the textual command list write: /command_list";
            welcome += "\n\nFor the command button list write: /command";
            bot.sendMessage(chat_id, welcome, "");
        }

        if (text == "/command_list") {
            String command_list = "Textual commands list:\n";
            command_list += "/alert to alert people actively \n";
            command_list += "/temperature to get home tempemperature \n";
            command_list += "/humidity to get tempemperature home humidity \n";
            command_list += "/testRGB test all rgb color on led \n";
            command_list += "/upper_bound instruction to set upper bound\n";
            command_list += "/lower_bound instruction to set lower bound\n";
            command_list += "/state to get the temperature bounds \n";
            command_list += "/help to recive help about iot passive thermostat\n";
            command_list += "/command to display the command buttons \n";
            bot.sendMessage(chat_id, command_list, "");
        }

        /*if u want to add a new command on telegram follow this pattern
          if (text == "<action>") {
          // connect other sensor like a audio sensor for measuring a noise in a room
          if(sensor.sense() > limit){
            //do something
           }
          bot.sendMessage(chat_id, "Hello i'm a message", "");
          }
        */
    }
}

// function for change color for passive notification
void trasactionRGB(unsigned int rgbColourEnd[3]) {
    unsigned int rgbColour[3];
    // Start off with red.
    rgbColour[0] = rgbColourEnd[0];
    rgbColour[1] = rgbColourEnd[1];
    rgbColour[2] = rgbColourEnd[2];
    // Choose the colours to increment and decrement.
    for (int decColour = 0; decColour < 3; decColour += 1) {
        int incColour = decColour == 2 ? 0 : decColour + 1;
        // cross-fade the two colours.
        for (int i = 0; i < 255; i += 1) {
            rgbColour[decColour] -= 1;
            rgbColour[incColour] += 1;
            RGB_color(rgbColour[0], rgbColour[1], rgbColour[2]);
            delay(CHANGE_DELAY); // speed of change led on rgb lamp
        }
    }
}

//upload temperature humidity data to thingspeak.com
void uploadTemperatureHumidity() {
    float dhtTempC = dht.readTempC();
    float dhtHumidity = dht.readHumidity(); // Reading humidity in %
    if (!client_thingspeak.connect(host_thingspeak, httpPort)) {
        Serial.println("connection failed thingspeak");
        return;
    }
    Serial.println("upload");
    // Four values (field1 field2 field3 field4) have been set in thingspeak.com
    client_thingspeak.print(String("GET ") + "/update?api_key=" + api_key_thingspeak + "&field1=" + dhtTempC + "&field2=" + dhtHumidity + " HTTP/1.1\r\n" + "Host: " + host_thingspeak + "\r\n" + "Connection: close\r\n\r\n");
    while (client_thingspeak.available()) {
        String line = client_thingspeak.readStringUntil('\r');
        Serial.print(line);
    }
}

// HUE INTEGRATION

/* setHue() is a command function, which needs to be passed a light number and a
   properly formatted command string in JSON format.
   It then makes a simple HTTP PUT request to the Bridge at the IP specified at the start.

   Made according to philips hue api site: https://developers.meethue.com/develop/get-started-2/
*/
boolean setHue(int lightNum, String command)
{
    Serial.println("setHue");
    if (client_hue.connect(server, 80))
    {
        Serial.println(F("connected to server"));
        while (client_hue.connected() && WiFi.status() == WL_CONNECTED)
        {
            client_hue.print(F("PUT /api/"));
            client_hue.print(hueUsername);
            client_hue.print(F("/lights/"));
            client_hue.print(lightNum);  // hueLight zero based, add 1
            client_hue.println(F("/state HTTP/1.1"));
            client_hue.println(F("keep-alive"));
            client_hue.print(F("Host: "));
            client_hue.println(hueHubIP);
            client_hue.print(F("Content-Length: "));
            client_hue.println(command.length());
            client_hue.println(F("Content-Type: text/plain;charset=UTF-8"));
            client_hue.println();  // blank line before body
            client_hue.println(command);  // Hue command
        }
        client_hue.stop();
        return true;  // command executed
    }
    else
        return false;  // command failed
}


// loop function listen the message on the bot and pilot the passive notification on the rgb led
void loop() {

    // section that scan new messages on telegram bot
    if (millis() > lastTimeBotRan + botRequestDelay)  {
        int numNewMessages = bot.getUpdates(bot.last_message_received + 1);
        while (numNewMessages) {
            Serial.println("got response");
            handleNewMessages(numNewMessages);
            numNewMessages = bot.getUpdates(bot.last_message_received + 1);
        }
        lastTimeBotRan = millis();
    }
    // action related to sensor
    float dhtTempC = dht.readTempC();
    if (lowerBound < dhtTempC && dhtTempC < upperBound) {
        trasactionRGB(green); // led on node mcu
        //setHue(1, hueWhite); // philips hue lamp
    }
    if (dhtTempC > upperBound) {
        trasactionRGB(red); // led on node mcu
        //setHue(1, hueRed); // philips hue lamp 1
    }
    if (lowerBound > dhtTempC) {
        trasactionRGB(blue); // led on node mcu
        //setHue(1, hueBlue); // philips hue lamp
    }
    // action related on board button
    buttonState = digitalRead(button); // read the state of the button
    Serial.println(buttonState);
    // reset the bound of temperature and the light of consequence turn to white
    if (buttonState == HIGH) {
        Serial.println("Reset pressed");
        for (int i = 0; i < 6; i++) { // notify the user that have press the button
            RGB_color(255, 0, 0); // Red
            delay(200);
            RGB_color(0, 0, 0); // Red
            delay(200);
        }
        // set the bound for have the white lamp
        lowerBound -= 5;
        upperBound += 5;
        bot.sendMessage(CHAT_ID, "Warning: User play reset button.\nRemember to change the temperature bound!", "");
    }
    //Upload Temperature Humidity every 60 seconds in thingspeak.com
    if (millis() - differenceUpload > uploadTime) {
        uploadTemperatureHumidity();
        differenceUpload = millis();
    }
}

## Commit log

2021-04-16 add led control lamp control
2021-04-21 upload old stuff organizex, also add the model 3d of box
    [COPERCHIO.stl, scatola.stl]
2021-04-21 renamed stuff
    [box.stl, cover.stl]
2021-04-21 add library for extra project sensor
    [MQ131_Arduino_Uno_circuit.fzz, Sensitivity_curves.xlsx]
2021-04-22 thingspeak integration to make graph online,
    fix on hue client
    [firmware.ino]
2021-04-23 Add files via upload
    Result of the test presented in the paper
    [TEST.xlsx]
2021-05-03 fix row in test xls
    [TEST.xlsx]
2021-05-03 fix firmware comment add the thingspeak integration and add a library to control the rgb led
    [Fade.ino, Flash.ino, firmware.ino]
2021-06-04 fix the firmware after telegram update with wifisecure
    [firmware1.1.ino]

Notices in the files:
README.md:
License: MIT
